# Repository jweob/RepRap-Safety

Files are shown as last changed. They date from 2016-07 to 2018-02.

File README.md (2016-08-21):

RepRap safety cutoff
Copyright John O'Brien 2016
jweob@cantab.net 2016-07-16

This program is free software: you can redistribute it and/or modify
 it under the terms of the GNU General Public License as published by
 the Free Software Foundation, either version 3 of the License, or
 (at your option) any later version.

 This program is distributed in the hope that it will be useful,
 but WITHOUT ANY WARRANTY; without even the implied warranty of
 MERCHANTABILITY or FITNESS FOR A PARTICULAR PURPOSE.  See the
 GNU General Public License for more details.

 You should have received a copy of the GNU General Public License
 along with this program.  If not, see <http://www.gnu.org/licenses/>

Turns off the power supply to a RepRap using a relay if any of the following five conditions are met

1. Secondary thermistor reads a temperature above a set threshold

2. Bed heat signal is on for more than a set period of time

3. Hot end is on for more than a set period of time

4. Bed power supply positive voltage is below a threshold, indicating a bad connection

5. Bed power supply negative voltage is above a thrshold, indicating a bad connection

More information at http://jweoblog.com/?p=835 and More information at http://jweoblog.com/?p=922

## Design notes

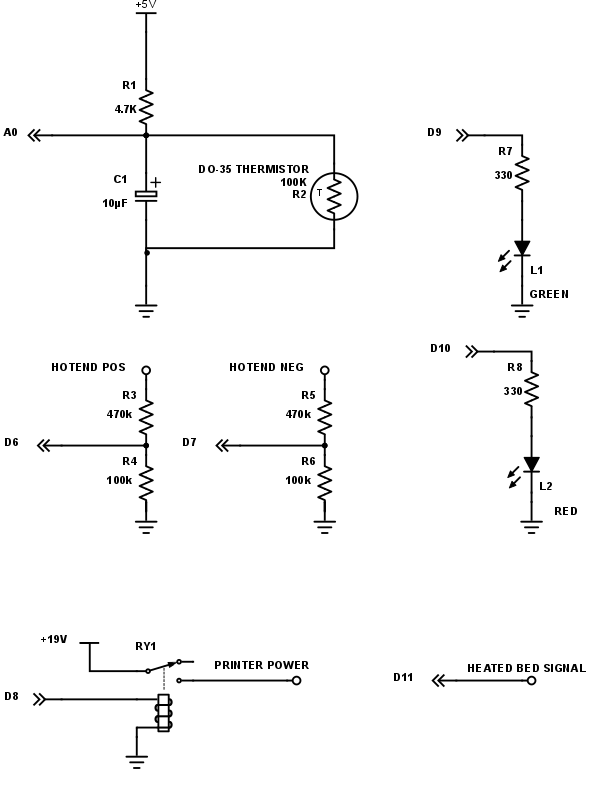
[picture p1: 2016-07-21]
pin-schematic.png

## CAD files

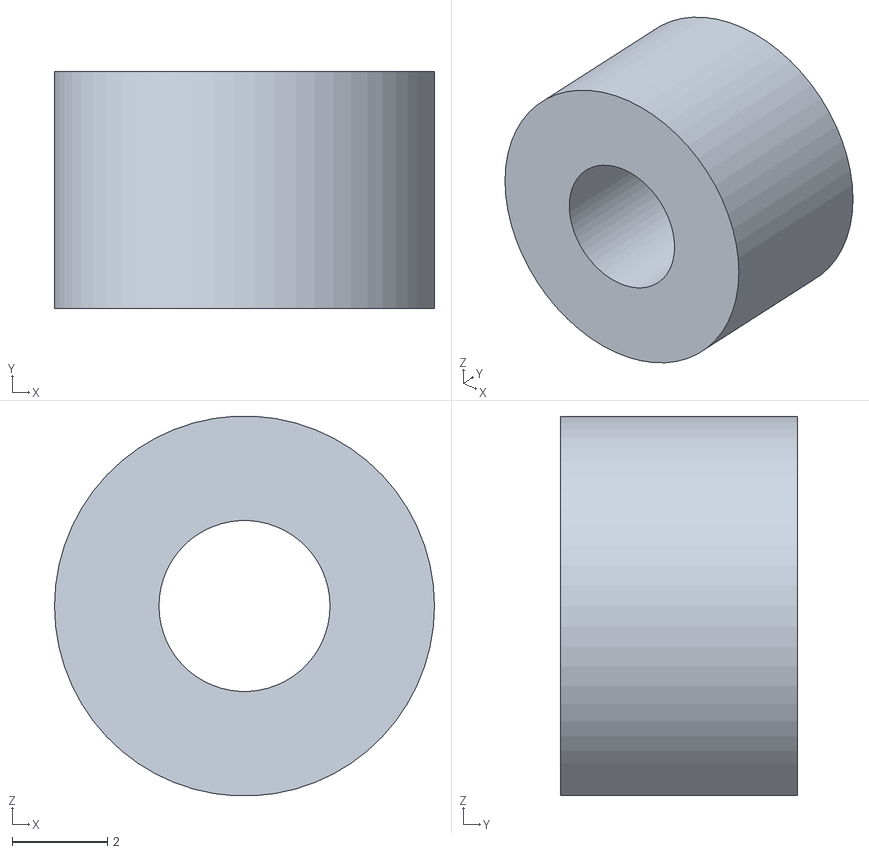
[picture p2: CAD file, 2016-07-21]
mounts/pi_stud_x2.stl
8.00 x 5.00 x 7.99

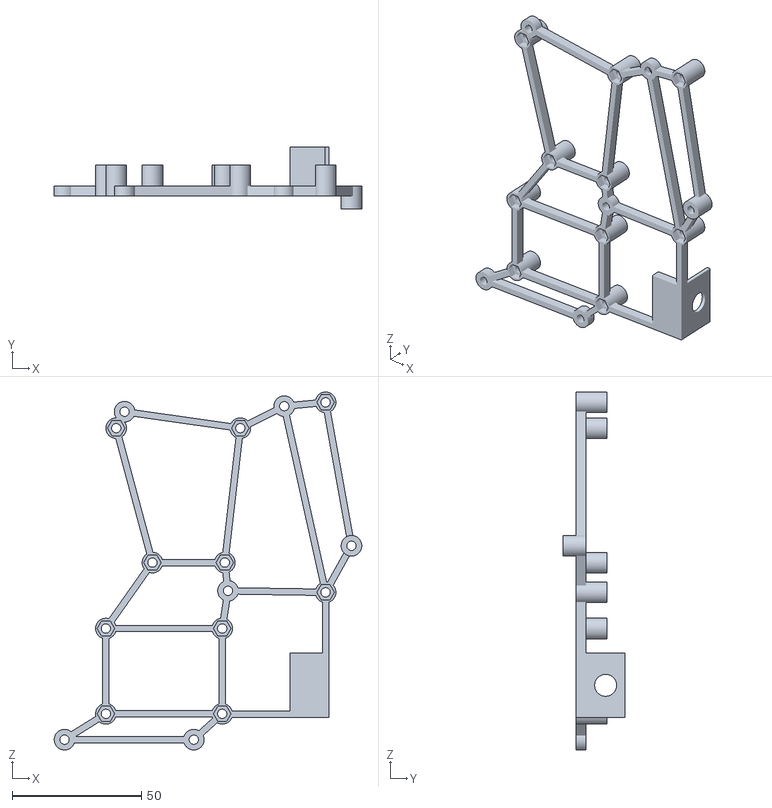
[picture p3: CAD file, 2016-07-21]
mounts/mount_x1.stl
119.0 x 24.0 x 138.5

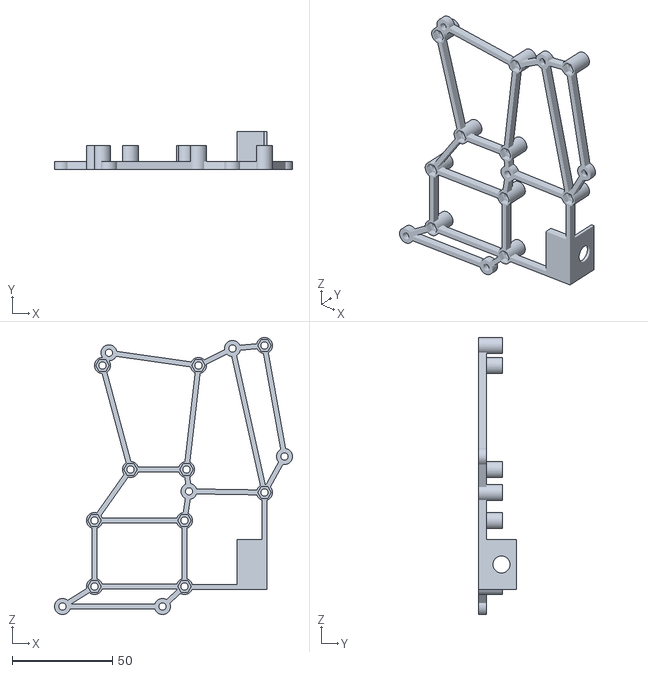
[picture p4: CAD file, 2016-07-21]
mounts/mount_clip_x4.stl
119.0 x 19.0 x 138.5

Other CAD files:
mounts/mount.x_t
mounts/pi_stud_x2.x_t

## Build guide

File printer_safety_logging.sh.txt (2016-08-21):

#1/bin/bash
echo "Safety logging active"
echo "Safety logger Pi switched on at: " >> /home/pi/safety_log.txt
date '+%A %D %X' >> /home/pi/safety_log.txt
echo "" >> /home/pi/safety_log.txt
cat /dev/ttyACM0 >> /home/pi/safety_log.txt

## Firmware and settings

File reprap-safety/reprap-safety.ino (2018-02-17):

/*
  RepRap safety cutoff
  Copyright John O'Brien 2016
  jweob@cantab.net 2016-07-16

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

  Turns off the power supply to a RepRap using a relay if any of the following three conditions are met
  1. Secondary thermistor reads a temperature above a set threshold
  2. Bed heat signal is on for more than a set period of time
  3. Hote end is on for more than a set period of time


*/

#include <avr/pgmspace.h>

// Macros
#define BED_TIME_THRESH 600000 // If heated bed is on for longer than this printer will shut down
#define EXT_TIME_THRESH 60000 // If extruder is on for longer than this printer will shut down
#define EXT_TEMP_THRESH 250 // If the hotend temperature exceeds this value the printer will shut down
#define OPEN_CIRCUIT_TEMP 5 // Open circuit will read as 0C. Short circuit will read as a negative temperature Turn printer off if measured temperature goes below  this temperature


#define OVERSAMPLEBITS 4 // additional bits of precision required for temperature sampling (n)
#define OVERSAMPLENR 16 // 2^n where n is the additional bits of precision required
#define OVERSAMPLES 256 // 4^n where n is the additional bits of precision required


#define PGM_RD_W(x)   (short)pgm_read_word(&x) // Macro for reading the thermistor table
#define heater_ttbllen_map (sizeof(temptable)/sizeof(*temptable))

#define VOLTCONVERT 0.027 // Number of volts per ADC point. E.g. if the potential divider is 470k and 100k then it is 5/100*570/1024 = 0.0278. I had to adjust this slightly experimentally to match the reading on a voltmeter
#define MINPOSVOLT 18 // Analog pins on bed positive power supply will shut off if read below this value
#define MAXNEGVOLT 1 // Analog pins on bed negative power supply will shut off if read above this value

#define LOGINTERVAL 1000 // Logging interval in milliseconds

unsigned long raw = 0; // Holds the output of the oversample function
unsigned long currentMillis = 0; // Captures the current milliseconds since the arduino was switched on
unsigned long prevLogMillis = 0; // Captures when the arduino last logged to serial
unsigned long bedStartMillis = 0; // Captures when the bed was last turned on
unsigned long extStartMillis = 0; // Captures when the hotend was last turned on
boolean previousBedOn = false; // Was the bed on the last time the arduino checked
boolean previousExtOn = false; // Was the hotend on the last time the arduino checked
unsigned long extOnForMillis = 0; // Time the extruder has been on for
unsigned long bedOnForMillis = 0; // Time the bed has been on for
float powerVolt = 0;
float bedPosVolt = 0;
float bedNegVolt = 0;


const unsigned long bedInterval = BED_TIME_THRESH; // If the interval between the last time the bed was switched on and the current milliseconds is greater than this, switch off
const unsigned long extInterval = EXT_TIME_THRESH; // Likewise for hotend
float celsius = 0; // Holds the output of analog2temp
const float tempThresh = EXT_TEMP_THRESH; // Holds the temperature threshold for cutoff

// Printer currently only has two states, could add more e.g. startup if necessary
enum printerStates {
  OK,
  PROBLEM
};

// Current and previous states
int currentState = OK;
int oldState = OK;
int problemType = 0;

// Pin definitions
int extThermPin = 0; // Output from the potential divider circuit which includes the thermistor
int bedHeatPosPin = 4; // Bed heater positive pin, scaled down using a potential divider
int bedHeatNegPin = 2; // Bed heater negative pin, scaled down using a potential divider
int powerPin = 5; // Power supply, scaled down using a potential divider
int relayPin = 8; // Pin attached to relay driver circuit. Low signal activates relay and turns on printer
int goodLedPin = 9; // Green LED to indicate printer in "OK" state
int badLedPin = 10; // Red LED to indicate something printer in "PROBLEM" state
int bedSignalPin = 11; // The logical signal coming from the Melzi which activates the heated bed. High means the bed is on
int exPosPin = 6; // The hotend heater is driven by the voltage across two terminals on the Melzi. When the heater is off both terminals are at ~19V.
int exNegPin = 7; // When the heater is on the negative pin is driven to ground
// We need to measure both pins so that we can tell the difference between there being no power to the printer (both pins low) and the hotend being on (positive pin high, negative low)

// Function signatures
static unsigned long oversample(int pin); // Oversamples an analog pin to get better precision
static float analog2temp(unsigned long raw); // Converts the reading from the oversample function into degrees celsius


// Thermistor table. This table is setup for the Extruder thermistor: Digikey 480-3137-ND which should be included in All Huxleys shipped after 25/2/14
// Table was generated using the RepRapPro Formula
const short temptable[][2] PROGMEM = {
  {
    23 * OVERSAMPLENR,    341
  }
  ,
  {
    25 * OVERSAMPLENR,    333
  }
  ,
  {
    27 * OVERSAMPLENR,    325
  }
  ,
  {
    28 * OVERSAMPLENR,    322
  }
  ,
  {
    31 * OVERSAMPLENR,    313
  }
  ,
  {
    33 * OVERSAMPLENR,    307
  }
  ,
  {
    35 * OVERSAMPLENR,    302
  }
  ,
  {
    38 * OVERSAMPLENR,    295
  }
  ,
  {
    41 * OVERSAMPLENR,    288
  }
  ,
  {
    44 * OVERSAMPLENR,    282
  }
  ,
  {
    48 * OVERSAMPLENR,    275
  }
  ,
  {
    52 * OVERSAMPLENR,    269
  }
  ,
  {
    56 * OVERSAMPLENR,    264
  }
  ,
  {
    61 * OVERSAMPLENR,    257
  }
  ,
  {
    66 * OVERSAMPLENR,    251
  }
  ,
  {
    71 * OVERSAMPLENR,    246
  }
  ,
  {
    78 * OVERSAMPLENR,    239
  }
  ,
  {
    84 * OVERSAMPLENR,    233
  }
  ,
  {
    92 * OVERSAMPLENR,    227
  }
  ,
  {
    100 * OVERSAMPLENR,    221
  }
  ,
  {
    109 * OVERSAMPLENR,    216
  }
  ,
  {
    120 * OVERSAMPLENR,    209
  }
  ,
  {
    131 * OVERSAMPLENR,    203
  }
  ,
  {
    143 * OVERSAMPLENR,    198
  }
  ,
  {
    156 * OVERSAMPLENR,    192
  }
  ,
  {
    171 * OVERSAMPLENR,    186
  }
  ,
  {
    187 * OVERSAMPLENR,    180
  }
  ,
  {
    205 * OVERSAMPLENR,    174
  }
  ,
  {
    224 * OVERSAMPLENR,    169
  }
  ,
  {
    245 * OVERSAMPLENR,    163
  }
  ,
  {
    268 * OVERSAMPLENR,    157
  }
  ,
  {
    293 * OVERSAMPLENR,    152
  }
  ,
  {
    320 * OVERSAMPLENR,    146
  }
  ,
  {
    348 * OVERSAMPLENR,    141
  }
  ,
  {
    379 * OVERSAMPLENR,    135
  }
  ,
  {
    411 * OVERSAMPLENR,    129
  }
  ,
  {
    445 * OVERSAMPLENR,    124
  }
  ,
  {
    480 * OVERSAMPLENR,    118
  }
  ,
  {
    516 * OVERSAMPLENR,    113
  }
  ,
  {
    553 * OVERSAMPLENR,    108
  }
  ,
  {
    591 * OVERSAMPLENR,    102
  }
  ,
  {
    628 * OVERSAMPLENR,     97
  }
  ,
  {
    665 * OVERSAMPLENR,     92
  }
  ,
  {
    702 * OVERSAMPLENR,     86
  }
  ,
  {
    737 * OVERSAMPLENR,     81
  }
  ,
  {
    770 * OVERSAMPLENR,     76
  }
  ,
  {
    801 * OVERSAMPLENR,     71
  }
  ,
  {
    830 * OVERSAMPLENR,     65
  }
  ,
  {
    857 * OVERSAMPLENR,     60
  }
  ,
  {
    881 * OVERSAMPLENR,     55
  }
  ,
  {
    903 * OVERSAMPLENR,     50
  }
  ,
  {
    922 * OVERSAMPLENR,     45
  }
  ,
  {
    939 * OVERSAMPLENR,     40
  }
  ,
  {
    954 * OVERSAMPLENR,     35
  }
  ,
  {
    966 * OVERSAMPLENR,     30
  }
  ,
  {
    977 * OVERSAMPLENR,     25
  }
  ,
  {
    985 * OVERSAMPLENR,     21
  }
  ,
  {
    993 * OVERSAMPLENR,     16
  }
  ,
  {
    999 * OVERSAMPLENR,     11
  }
  ,
  {
    1004 * OVERSAMPLENR,      6
  }
  ,
  {
    1008 * OVERSAMPLENR,      0
  }
};


// Pointer to thermistor table
short (*tt)[][2] = (short (*)[][2])(temptable);

void setup()
{
  Serial.begin(9600);
  while (!Serial);
  Serial.println();
  Serial.println();
  Serial.println();
  Serial.println("Arduino reset. Begin logging.");
  pinMode(relayPin, OUTPUT);
  pinMode(goodLedPin, OUTPUT);
  pinMode(badLedPin, OUTPUT);
  pinMode(bedSignalPin, INPUT);
  pinMode(exPosPin, INPUT);
  pinMode(exNegPin, INPUT);

  // Initial setup of output pins
  digitalWrite(goodLedPin, HIGH);
  digitalWrite(badLedPin, LOW);
  digitalWrite(relayPin, LOW);

  delay( 1000 ); // Give voltage on the A0 pin time to settle
}


void loop()
{
  if (currentState == OK) {
    currentMillis = millis(); // Get current time
    raw = oversample(extThermPin);    // read the input pin
    celsius = analog2temp(raw);

    // Check for overtemperature
    if (celsius > tempThresh) {
      Serial.print("Temperature exceeded with temp of ");
      Serial.print(celsius);
      Serial.print(" degC. Switching off.");
      currentState = PROBLEM;
      problemType = 1;
    }

    // Check for open or closed circuits
    if (celsius < OPEN_CIRCUIT_TEMP) {
      Serial.println("Short or open circuit. Switching off.");
      currentState = PROBLEM;
      problemType = 1;
    }

    // Check whether bed has been on too long
    if (digitalRead(bedSignalPin) == HIGH) {
      bedOnForMillis = currentMillis - bedStartMillis;
      if (previousBedOn) {
        if (bedOnForMillis > bedInterval) {
          Serial.print("Bed heater on too long (");
          Serial.print(bedOnForMillis);
          Serial.println("ms). Switiching off.");
          currentState = PROBLEM;
          problemType = 2;
        }
      }
      else {
        previousBedOn = true;
        bedStartMillis = currentMillis;
      }
    }
    else {
      if (previousBedOn) {
        bedStartMillis = 0;
        previousBedOn = false;
      }
    }

    // Check if hotend has been on too long
    if (digitalRead(exPosPin) == HIGH && digitalRead(exNegPin) == LOW) {
      extOnForMillis = currentMillis - extStartMillis;
      if (previousExtOn) {
        if (extOnForMillis > extInterval) {
          Serial.print("Hotend on too long (");
          Serial.print(extOnForMillis);
          Serial.println("ms). Switiching off");
          currentState = PROBLEM;
          problemType = 3;
        }
      }
      else {
        previousExtOn = true;
        extStartMillis = currentMillis;
      }
    }
    else {
      if (previousExtOn) {
        extOnForMillis = 0;
        previousExtOn = false;
      }
    }

    powerVolt = analogRead(powerPin) * VOLTCONVERT;
    bedPosVolt = analogRead(bedHeatPosPin) * VOLTCONVERT;
    bedNegVolt = analogRead(bedHeatNegPin) * VOLTCONVERT;
    // Check for sparking on bed
    if (bedPosVolt < MINPOSVOLT) {
      Serial.println("Bed positive voltage problem");
      Serial.print("Bed pos voltage of ");
      Serial.print(bedPosVolt);
      Serial.print("V; Bed neg voltage of ");
      Serial.print(bedNegVolt);
      Serial.print("V; Power supply voltage of ");
      Serial.print(powerVolt);
      Serial.println("V. Switching Off");
      currentState = PROBLEM;
      problemType = 4;

    }
    /*

        if(bedNegVolt > MAXNEGVOLT) {
      Serial.println("Bed negative voltage problem");
      Serial.print("Bed pos voltage of ");
      Serial.print(bedPosVolt);
      Serial.print("V; Bed neg voltage of ");
      Serial.print(bedNegVolt);
      Serial.print("V; Power supply voltage of ");
      Serial.print(powerVolt);
      Serial.println("V. Switching Off");
      currentState = PROBLEM;
      problemType = 5;

      }
    */


    if ((currentMillis - prevLogMillis) > LOGINTERVAL) {
      Serial.print("OK with time @ ");
      Serial.print(currentMillis);
      Serial.print("ms. Hotend @ ");
      Serial.print(celsius);
      Serial.print("C; ");
      if (previousExtOn) {
        Serial.print("Hotend on for ");
        Serial.print(extOnForMillis);
        Serial.print("ms; ");
      }
      else {
        Serial.print("Hotend off; ");
      }
      if (previousBedOn) {
        Serial.print("Bed on for ");
        Serial.print(bedOnForMillis);
        Serial.print("ms; ");
      }
      else {
        Serial.print("Bed off; ");
      }
      Serial.print("Bed pos @ ");
      Serial.print(bedPosVolt);
      Serial.print("V; Bed neg @ ");
      Serial.print(bedNegVolt);
      Serial.print("V; Power supply @ ");
      Serial.print(powerVolt);
      Serial.println("V");
      prevLogMillis = currentMillis;
    }

  }

  // If the state has changed, update the pins
  if (currentState != oldState) {

    switch (currentState) {
      case OK:
        digitalWrite(goodLedPin, HIGH);
        digitalWrite(badLedPin, LOW);
        digitalWrite(relayPin, LOW);
        break;
      case PROBLEM:
        digitalWrite(goodLedPin, LOW);
        digitalWrite(relayPin, HIGH);
        break;
      default:
        digitalWrite(goodLedPin, LOW);
        digitalWrite(relayPin, HIGH);
        break;
    }
    oldState = currentState;
  }

  if (currentState == PROBLEM) {
    for (int rep = 0; rep < problemType; rep++) {
      digitalWrite(badLedPin, HIGH);
      delay(200);
      digitalWrite(badLedPin, LOW);
      delay(500);
    }
    delay(1000);

  }
}

static unsigned long oversample(int pin) {
  // Oversampling concepts from http://www.electricrcaircraftguy.com/2014/05/using-arduino-unos-built-in-16-bit-adc.html and http://www.atmel.com/Images/doc8003.pdf
  int i = 0;
  unsigned long acc = 0;
  // Read the thermistor muiltiple times and accumulate the result
  for (i = 0; i < OVERSAMPLES; i++)
  {
    acc += analogRead(pin);
  }
  acc = acc >> OVERSAMPLEBITS; // Divide the accumulated reading by performing a right bit shift

  return acc;
}


static float analog2temp(unsigned long raw) {
  // MODIFIED FROM MARLIN https://github.com/MarlinFirmware/Marlin
  // Derived from RepRap FiveD extruder::getTemperature()
  int i;


  for (i = 1; i < heater_ttbllen_map; i++)
  {
    if (PGM_RD_W((*tt)[i][0]) > raw)
    {
      celsius = PGM_RD_W((*tt)[i - 1][1]) +
                (raw - PGM_RD_W((*tt)[i - 1][0])) *
                (float)(PGM_RD_W((*tt)[i][1]) - PGM_RD_W((*tt)[i - 1][1])) /
                (float)(PGM_RD_W((*tt)[i][0]) - PGM_RD_W((*tt)[i - 1][0]));
      break;
    }
  }

  // Overflow: Set to last value in the table
  if (i == heater_ttbllen_map) celsius = PGM_RD_W((*tt)[i - 1][1]);

  return celsius;

}

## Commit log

2016-07-15 Working temperature sensing (no oversampling)
2016-07-17 Temperature cutoff, bed cutoff and hotened cutoff
2016-07-21 Added license and 3D files for mounts
    [mount.x_t, mount_clip_x4.stl, mount_x1.stl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]
2016-07-21 3D files
    [pi_stud_x2.stl, pi_stud_x2.x_t]
2016-08-16 Added code to protect against bad bed connections
2016-08-21 Bed sparking cutoff and improved serial logging
2016-08-21 Updated readme, included shell script for automaticly saving serial logs to a raspberry pi
2016-08-22 Flashing led to indicate type of cutoff
2018-02-17 Remove bed negative voltage cutoff
    Bed negative voltage was causing issues, removed
    [reprap-safety.ino]
2018-02-17 Pin update
    Changed pin assignments to get round dead pin on board
